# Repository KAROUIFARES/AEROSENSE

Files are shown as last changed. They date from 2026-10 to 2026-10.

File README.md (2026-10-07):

<div align="center">

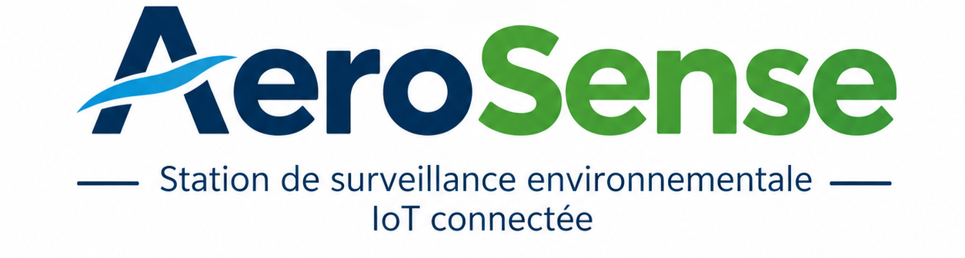
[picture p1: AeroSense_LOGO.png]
AeroSense Logo


# 🌤️ AeroSense - Station Météo Intelligente & Connectée IoT







<p align="center">
  <b>Système complet IoT de surveillance météorologique et de qualité de l'air ambiant</b><br>
  Microcontrôleur ESP32 • Capteur DHT11 • Afficheur LCD 1602 • Broker Cloud MQTT (TLS) • Dashboard Mobile Android Jetpack Compose
</p>

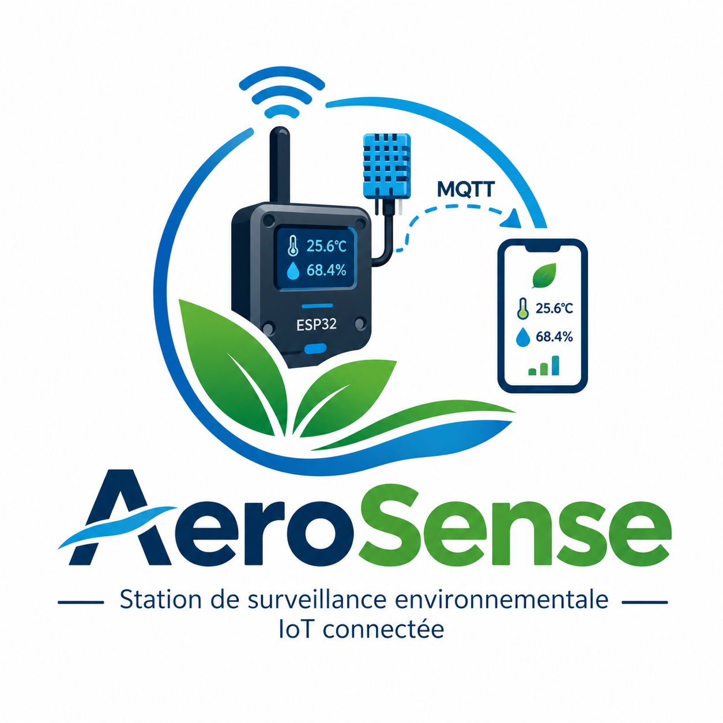
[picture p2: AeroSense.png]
AeroSense Présentation


</div>

---

## 📌 Présentation du Projet

**AeroSense** est une solution complète de station météorologique connectée pour la surveillance en temps réel de la température et de l'humidité relative. Le projet intègre l'ensemble de la chaîne de valeur d'un produit IoT :

1. **Système Embarqué (Hardware & Firmware) :**
   - Microcontrôleur **ESP32** assurant l'acquisition des données du capteur **DHT11**.
   - Affichage local instantané sur un écran **LCD 1602**.
   - Transmission sans fil sécurisée via le protocole **MQTT sur TLS/SSL (port 8883)** vers un broker Cloud.
2. **Conception Électronique & PCB :**
   - Schéma électronique et routage PCB sous **Proteus Design Suite 8**.
   - Vues et bibliothèques d'empreintes 3D (ESP32, TP4056, MT3608, USB-C, LCD 1602).
3. **Application Mobile (Dashboard Android) :**
   - Application native moderne développée en **Kotlin** avec **Jetpack Compose** et Material Design 3.
   - Connexion temps réel au broker MQTT, affichage de jauges animées, alertes automatiques et graphiques d'évolution.

---

## 📂 Structure du Répertoire

```text
AeroSense/
├── AeroSense_LOGO.png              # Logo officiel du projet
├── AeroSense.png                   # Bannière de présentation visuelle
├── Code_ESP32/                     # Firmware embarqué ESP32 (PlatformIO)
│   ├── README.md                   # Documentation technique détaillée du firmware
│   └── StationMeteo/
│       ├── platformio.ini          # Dépendances et configuration PlatformIO
│       └── src/
│           ├── config.h            # Configuration Wi-Fi et identifiants MQTT
│           └── main.cpp            # Code source principal commenté
├── ConceptionElectrique/           # Schématique et conception PCB (Proteus)
│   └── Station Météo IoT.pdsprj    # Fichier projet Proteus 8
├── Dashboard_AndroidApp/           # Application mobile Android (Jetpack Compose)
│   ├── app/src/main/
│   │   ├── java/com/.../           # Code source Kotlin (ViewModel, UI, MQTT)
│   │   └── res/                    # Ressources visuelles, icônes, thèmes
│   └── build.gradle.kts
└── Doc/                            # Documentation matérielle & bibliothèques EDA
    ├── PCB_Views/                  # Vues du circuit imprimé (PDF)
    └── Proteus_Library/            # Modèles et empreintes CAO (ESP32, LCD, etc.)
```

---

## ⚡ Architecture Système

```mermaid
flowchart LR
    A["Capteur DHT11\n(Température & Humidité)"] -->|GPIO 21| B["Microcontrôleur\nESP32"]
    B -->|Bus 4 bits| C["Afficheur LCD 1602\n(Affichage Local)"]
    B -->|Wi-Fi 802.11 b/g/n\nMQTTS / TLS Port 8883| D["Broker MQTT Cloud\n(EMQX / HiveMQ)"]
    D -->|Topic : aerosense/data\nFormat JSON| E["Application Android\nAeroSense Dashboard"]
```

---

## 🛠️ Démarrage Rapide

### 1. Firmware ESP32
Consultez la [documentation complète du firmware ESP32](./Code_ESP32/README.md).
- Rendez-vous dans `Code_ESP32/StationMeteo/`.
- Renseignez vos identifiants Wi-Fi et MQTT dans `src/config.h`.
- Téléversez avec PlatformIO : `pio run --target upload`.

### 2. Application Android Dashboard
- Ouvrez le dossier `Dashboard_AndroidApp` dans **Android Studio** (Giraffe ou version supérieure).
- Compilez et exécutez sur votre smartphone ou émulateur Android (API 26+).
- Configurez les paramètres du broker via la boîte de dialogue intégrée si nécessaire.

---

## 📄 Licence

Ce projet est sous licence MIT - voir le fichier [LICENSE](LICENSE) pour plus d'informations.

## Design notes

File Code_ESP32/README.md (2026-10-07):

# 🛰️ AeroSense - Firmware ESP32 (Station Météo IoT)

Ce sous-dossier contient le code source et la configuration PlatformIO du firmware embarqué sur le microcontrôleur **ESP32** pour la station météo connectée **AeroSense**.

---

## 📋 Table des Matières

1. [Vue d'ensemble](#-vue-densemble)
2. [Composants Matériels](#-composants-matériels)
3. [Schéma de Raccordement (Brochage / Pinout)](#-schéma-de-raccordement-brochage--pinout)
4. [Architecture Logicielle](#-architecture-logicielle)
5. [Configuration Réseau & MQTT](#-configuration-réseau--mqtt)
6. [Format des Données (Payload JSON)](#-format-des-données-payload-json)
7. [Compilation et Téléversement](#-compilation-et-téléversement)
8. [Surveillance & Débogage](#-surveillance--débogage)

---

## 🔍 Vue d'ensemble

Le firmware réalise les opérations suivantes :
- **Acquisition périodique** des mesures de température (°C) et d'humidité relative (%) via le capteur **DHT11**.
- **Affichage local temps réel** sur un écran **LCD 1602** (16 colonnes × 2 lignes) contrôlé en mode parallèle 4 bits.
- **Connexion Wi-Fi (802.11 b/g/n)** en mode station (STA).
- **Communication MQTTS sécurisée (TLS/SSL)** vers un broker Cloud (EMQX / HiveMQ Cloud sur le port 8883).
- **Publication automatique** de la télémétrie sous forme d'un objet JSON envoyé toutes les 5 secondes.

---

## 🔌 Composants Matériels

| Composant | Description | Rôle |
| :--- | :--- | :--- |
| **ESP32-WROOM-32** (NodeMCU-32S / ESP32 DevKit) | Microcontrôleur double cœur 240 MHz avec Wi-Fi & Bluetooth | Cœur de traitement et passerelle IoT |
| **DHT11** | Capteur d'ambiance numérique | Mesure de température et humidité relative |
| **LCD 1602** | Afficheur à cristaux liquides (contrôleur HD44780) | Affichage local des données et statuts |
| **Potentiomètre 10kΩ** | Potentiomètre rotatif | Ajustement du contraste du LCD (broche V0) |
| **Résistance de pull-up 4.7kΩ / 10kΩ** | Résistance de rappel | Ligne DATA du capteur DHT11 |

---

## 📌 Schéma de Raccordement (Brochage / Pinout)

### 1. Capteur DHT11
| Broche DHT11 | Broche ESP32 | Description |
| :--- | :--- | :--- |
| **VCC** | 3.3V / 5V | Alimentation capteur |
| **DATA** | **GPIO 21** | Signal de données (One-Wire) |
| **GND** | GND | Masse commune |

### 2. Afficheur LCD 1602 (Mode 4 bits)
| Broche LCD 1602 | Broche ESP32 / Circuit | Description |
| :--- | :--- | :--- |
| **Pin 1 (VSS)** | GND | Masse |
| **Pin 2 (VDD)** | 5V | Alimentation logique |
| **Pin 3 (V0)** | Curseur potentiomètre | Réglage du contraste |
| **Pin 4 (RS)** | **GPIO 27** | Register Select |
| **Pin 5 (RW)** | GND | Mode écriture (Read/Write mis à la masse) |
| **Pin 6 (E)** | **GPIO 26** | Enable (Validation) |
| **Pin 11 (D4)** | **GPIO 25** | Données bit 4 |
| **Pin 12 (D5)** | **GPIO 33** | Données bit 5 |
| **Pin 13 (D6)** | **GPIO 32** | Données bit 6 |
| **Pin 14 (D7)** | **GPIO 14** | Données bit 7 |
| **Pin 15 (A)** | 5V (via résistance 220Ω) | Rétroéclairage Anode (+) |
| **Pin 16 (K)** | GND | Rétroéclairage Cathode (-) |

---

## 🏗️ Architecture Logicielle

Le projet est structuré selon les standards **PlatformIO** :

```text
Code_ESP32/StationMeteo/
├── platformio.ini       # Configuration du projet, de la cible et des dépendances
├── include/             # Fichiers d'en-tête additionnels
├── lib/                 # Bibliothèques privées du projet
├── src/
│   ├── config.h         # Constantes de configuration Wi-Fi et broker MQTT
│   └── main.cpp         # Logique principale (Setup, Loop, MQTT, DHT, LCD)
└── test/                # Tests unitaires
```

### Dépendances (`platformio.ini`) :
- `adafruit/DHT sensor library@^1.4.7` : Pilote de communication avec le capteur DHT11.
- `arduino-libraries/LiquidCrystal@^1.0.7` : Gestion de l'écran LCD 1602 (standard HD44780).
- `knolleary/PubSubClient@^2.8` : Client MQTT léger pour microcontrôleurs.

---

## ⚙️ Configuration Réseau & MQTT

Toutes les informations d'identification se trouvent dans `src/config.h` :

```cpp
// --- Configuration Wi-Fi ---
#define WIFI_SSID     "VOTRE_SSID_WIFI"
#define WIFI_PASSWORD "VOTRE_MOT_DE_PASSE"

// --- Configuration Broker Cloud ---
#define MQTT_BROKER   "h1211a42.ala.eu-central-1.emqxsl.com" // Hôte EMQX / HiveMQ
#define MQTT_PORT     8883                                   // Port MQTTS chiffré TLS
#define MQTT_USER     "KAROUI"                               // Identifiant MQTT
#define MQTT_PASS     "aerosense"                            // Mot de passe MQTT

// --- Topics ---
#define MQTT_TOPIC_DATA "aerosense/data"                     // Topic de télémétrie
```

> **Sécurité TLS :** La couche réseau utilise `WiFiClientSecure` avec l'option `espClient.setInsecure()` pour dialoguer de façon chiffrée (SSL/TLS sur le port 8883) avec le broker sans nécessiter d'embarquer les certificats racines volumineux.

---

## 📦 Format des Données (Payload JSON)

Le firmware encapsule les mesures et les transmet sur le sujet MQTT `aerosense/data` :

```json
{
  "temp": 24.5,
  "hum": 60.0
}
```

- `temp` : Température mesurée en degrés Celsius (°C), arrondi à 1 décimale.
- `hum` : Humidité relative mesurée en pourcentage (%), arrondi à 1 décimale.

Ce format est directement décodé en temps réel par l'application Android **AeroSense Dashboard**.

---

## 🚀 Compilation et Téléversement

### Prérequis
- [Visual Studio Code](https://code.visualstudio.com/) avec l'extension **PlatformIO IDE**, ou la CLI PlatformIO (`pip install platformio`).

### Commandes en ligne de commande (CLI)

1. **Ouvrir le dossier :**
   ```bash
   cd Code_ESP32/StationMeteo
   ```

2. **Compiler le firmware :**
   ```bash
   pio run
   ```

3. **Téléverser sur l'ESP32 :**
   ```bash
   pio run --target upload
   ```

4. **Ouvrir le moniteur série (115200 bauds) :**
   ```bash
   pio device monitor -b 115200
   ```

---

## 🖥️ Surveillance & Débogage

Au démarrage, le moniteur série affiche le statut complet de la station :
```text
[AeroSense] Démarrage du système...
[AeroSense] Capteur DHT11 initialisé.
[AeroSense] Connexion au Wi-Fi : Topnet_12P8
.....
[AeroSense] Wi-Fi connecté !
[AeroSense] Adresse IP locale : 192.168.1.55
[AeroSense] Configuration MQTT appliquée.
[AeroSense] Tentative de connexion au broker MQTT... Connecté !
[AeroSense] Température: 24.2 °C | Humidité: 58.0 %
[AeroSense] Données publiées avec succès sur MQTT.
```

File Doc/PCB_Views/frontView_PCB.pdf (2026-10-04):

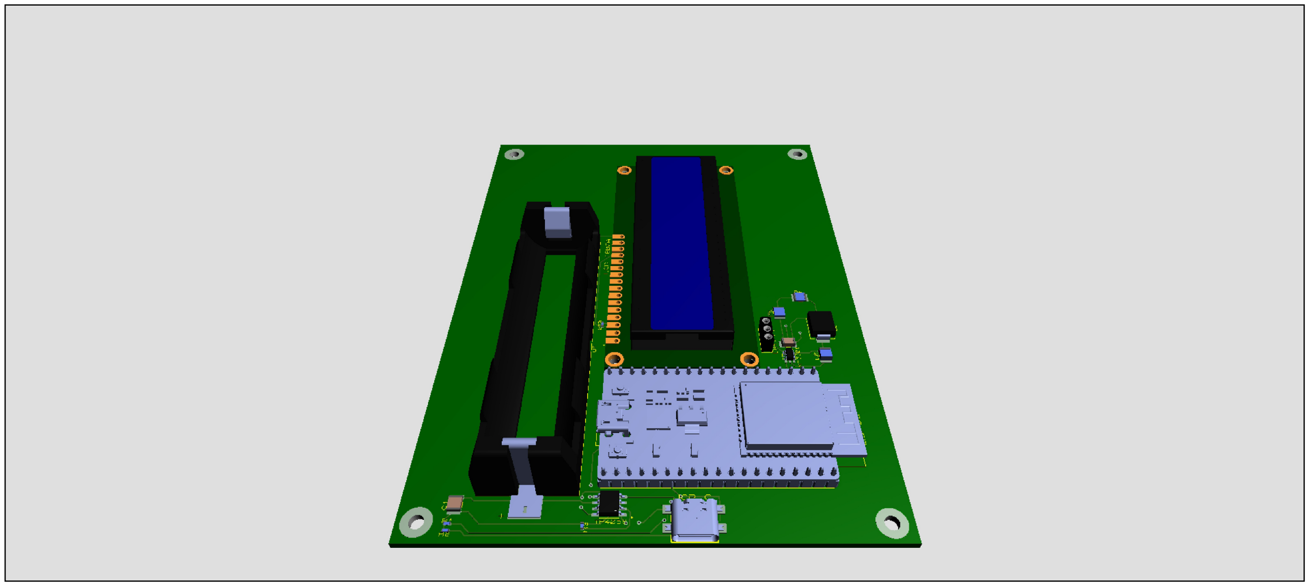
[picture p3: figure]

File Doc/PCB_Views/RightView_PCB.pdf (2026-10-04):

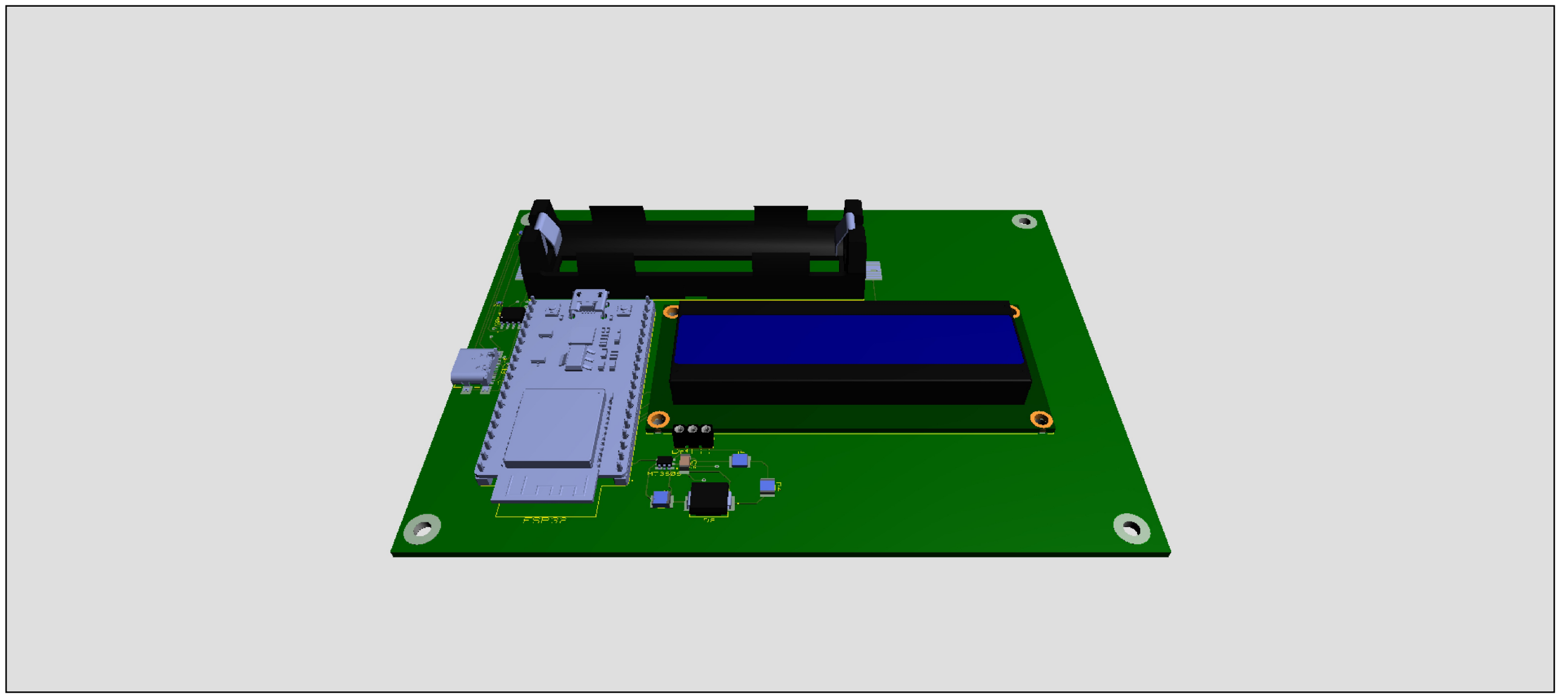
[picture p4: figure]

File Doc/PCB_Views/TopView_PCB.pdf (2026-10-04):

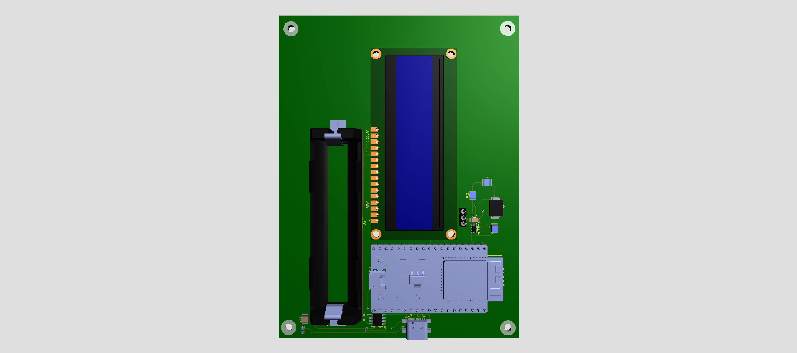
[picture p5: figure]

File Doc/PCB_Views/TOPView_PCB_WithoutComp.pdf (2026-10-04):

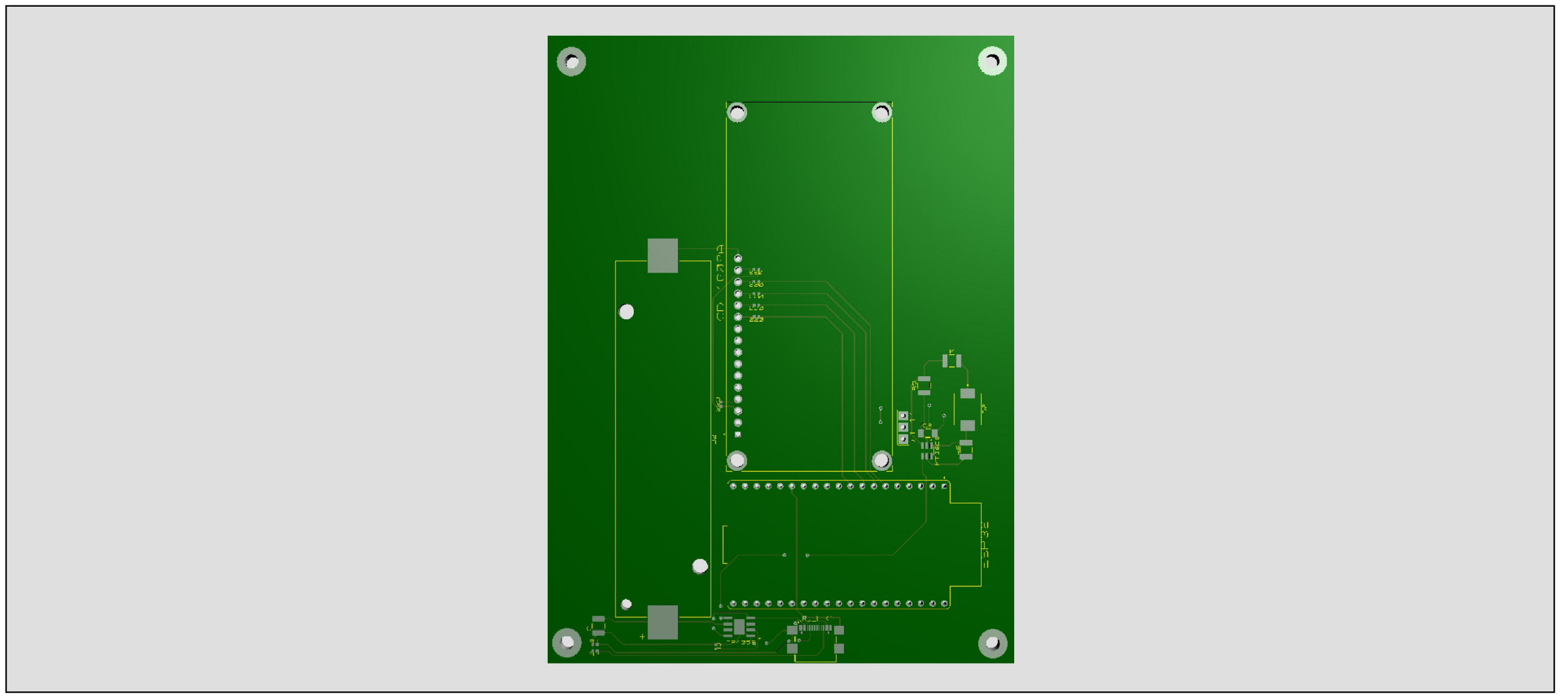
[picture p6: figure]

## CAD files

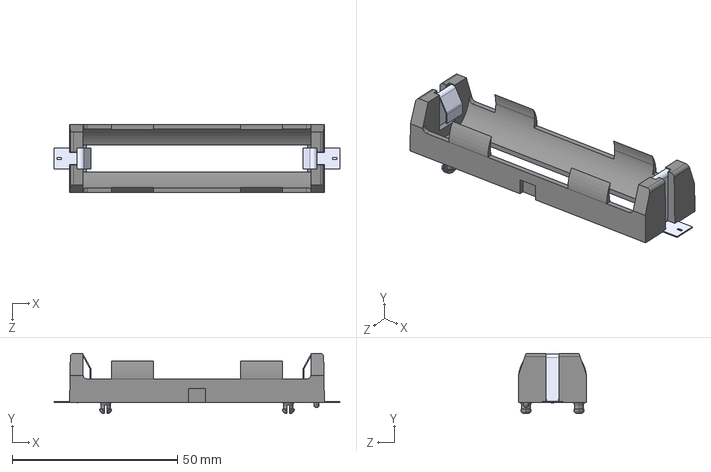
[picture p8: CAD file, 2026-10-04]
Doc/Proteus_Library/1042/1042.step
86.5 x 18.3 x 20.7 mm

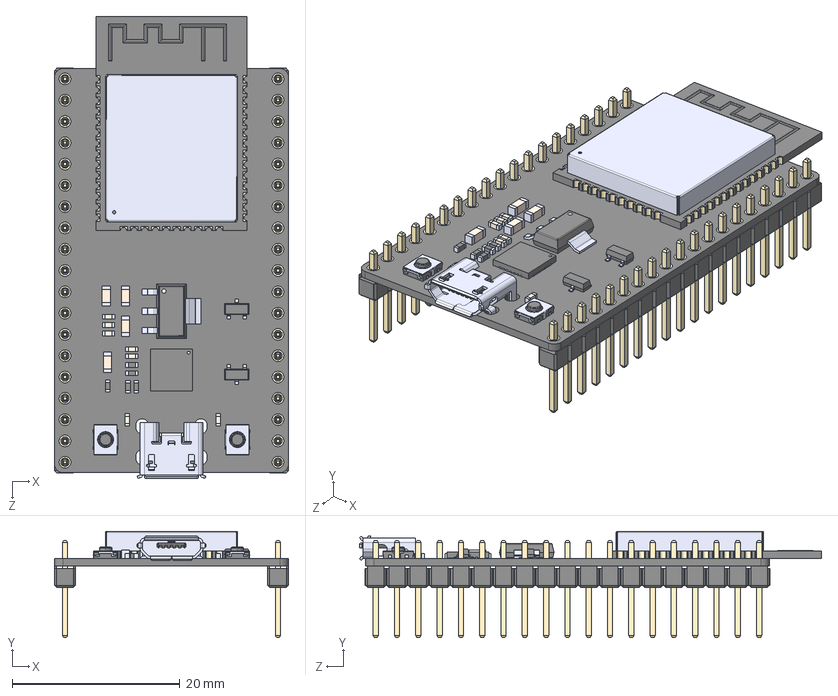
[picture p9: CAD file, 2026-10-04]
Doc/Proteus_Library/ESP32-DEVKITC-32E/ESP32-DEVKITC-32E.step
27.9 x 12.7 x 55.1 mm
board
header x 2
ESP32-WROOM-32D
micro usb
button x 2
CP2102N-A01-GQFN28
AMS1117-3.3
SS8050-G
components^DEVKIT V1 ESP32-WROOM-32

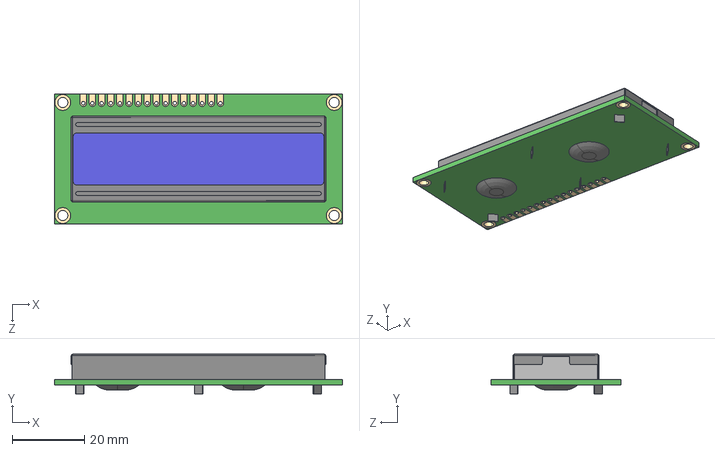
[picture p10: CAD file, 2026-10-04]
Doc/Proteus_Library/LCD_1602_2X16_BLUE-WHITE/LCD_1602_2X16_BLUE-WHITE.step
80.0 x 11.0 x 36.0 mm

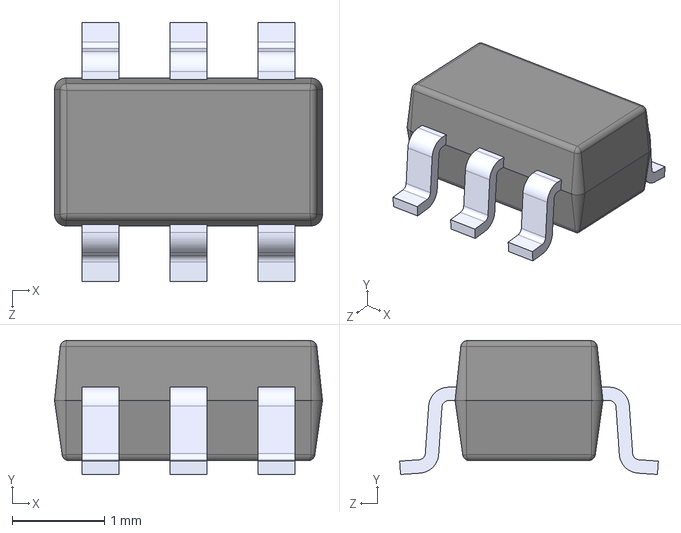
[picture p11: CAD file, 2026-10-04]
Doc/Proteus_Library/MT3608/MT3608.step
2.90 x 1.45 x 2.80 mm

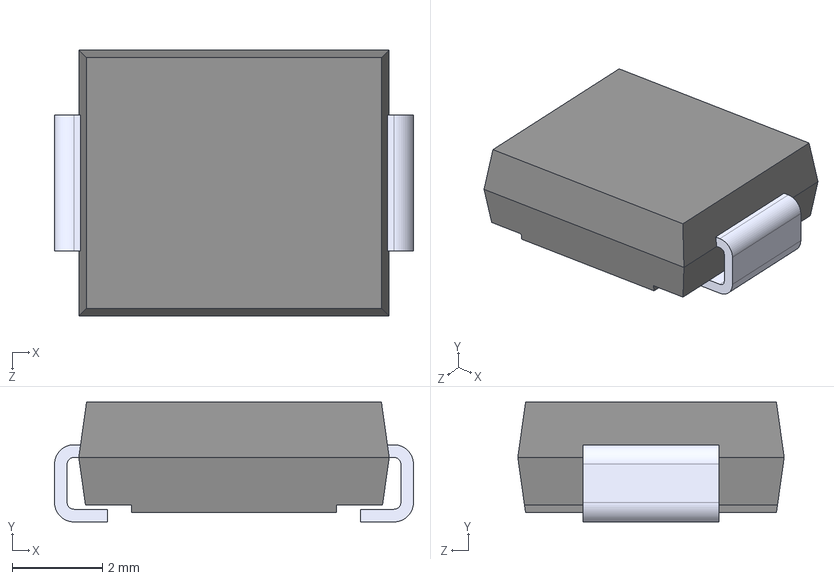
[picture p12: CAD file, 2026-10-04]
Doc/Proteus_Library/SS34/SS34.step
7.95 x 2.65 x 5.90 mm

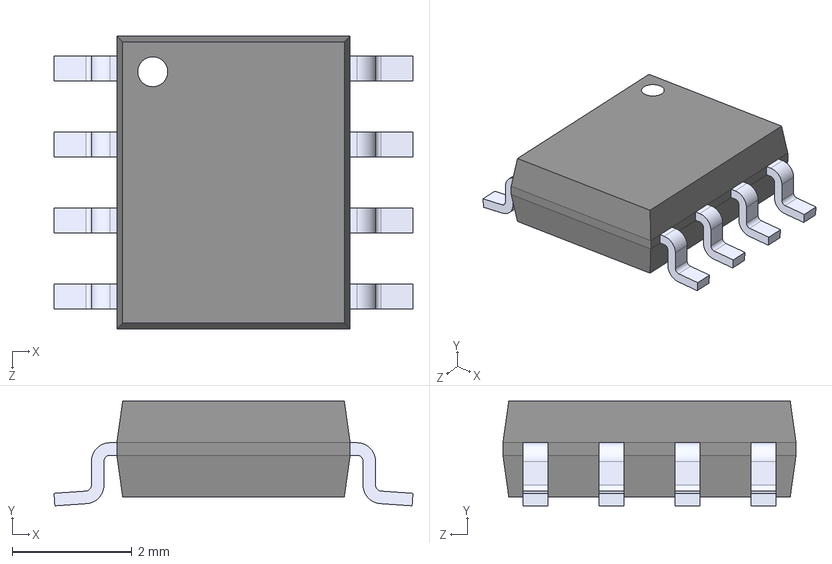
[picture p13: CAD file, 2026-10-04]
Doc/Proteus_Library/TP4056/TP4056.step
6.00 x 1.75 x 4.90 mm

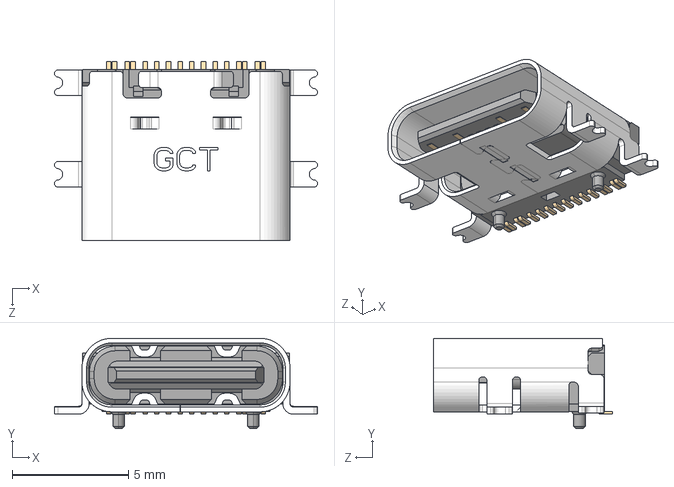
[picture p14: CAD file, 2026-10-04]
Doc/Proteus_Library/USB4110GFA/USB4110GFA.step
11.3 x 3.89 x 7.70 mm

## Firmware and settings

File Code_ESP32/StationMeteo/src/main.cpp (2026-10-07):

/**
 * ============================================================================
 * @file       main.cpp
 * @brief      Firmware ESP32 pour la Station Météo Connectée AeroSense
 * @project    AeroSense - Station Météo IoT
 * @details    Ce programme réalise :
 *             1. L'initialisation du matériel (Afficheur LCD 1602 et Capteur DHT11).
 *             2. La connexion au point d'accès Wi-Fi local.
 *             3. La connexion sécurisée en TLS/SSL au broker Cloud MQTT.
 *             4. La lecture périodique des mesures de température et d'humidité.
 *             5. L'encapsulation des mesures au format JSON et publication MQTT.
 *             6. L'affichage local et continu des grandeurs sur l'écran LCD.
 * ============================================================================
 */

#include <Arduino.h>
#include <DHT.h>
#include <LiquidCrystal.h>

#include <WiFi.h>
#include <WiFiClientSecure.h>
#include <PubSubClient.h>

#include "config.h"

// ============================================================================
// DÉFINITIONS MATÉRIELLES & BROCHAGE (PINOUT)
// ============================================================================

/** @brief Broche GPIO connectée à la ligne DATA du capteur DHT11 */
const int DHTPIN = 21;

/** @brief Type de capteur utilisé (DHT11, DHT22 ou DHT21) */
#define DHTTYPE DHT11

/**
 * @brief Instance du pilote pour le capteur d'ambiance DHT11
 * @param DHTPIN  GPIO 21 (Données avec résistance de pull-up)
 * @param DHTTYPE DHT11
 */
DHT dht(DHTPIN, DHTTYPE);

/**
 * @brief Configuration de l'afficheur LCD 16x2 en mode parallèle 4 bits
 * @param rs GPIO 27 (Register Select : choix commande ou donnée)
 * @param en GPIO 26 (Enable : impulsion de validation)
 * @param d4 GPIO 25 (Bus de données bit 4)
 * @param d5 GPIO 33 (Bus de données bit 5)
 * @param d6 GPIO 32 (Bus de données bit 6)
 * @param d7 GPIO 14 (Bus de données bit 7)
 */
LiquidCrystal lcd(27, 26, 25, 33, 32, 14);

// ============================================================================
// CLIENTS RÉSEAU & SÉCURITÉ TLS/MQTT
// ============================================================================

/** 
 * @brief Client Wi-Fi avec support de chiffrement TLS/SSL
 * @note  Permet d'établir une liaison sécurisée avec le port MQTTS 8883.
 */
WiFiClientSecure espClient;

/** 
 * @brief Gestionnaire de messages et protocole MQTT (PubSubClient)
 * @note  S'appuie sur le socket TLS fourni par espClient.
 */
PubSubClient client(espClient);

// ============================================================================
// PROTOTYPES DES FONCTIONS
// ============================================================================

/**
 * @brief Établit ou rétablit la connexion avec le broker MQTT Cloud.
 *        Boucle jusqu'à l'obtention d'une liaison active.
 */
void connectMQTT();

// ============================================================================
// INITIALISATION DU SYSTÈME (SETUP)
// ============================================================================

/**
 * @brief Initialisation des périphériques matériels et des interfaces réseau.
 *        Exécuté une seule fois à la mise sous tension ou au redémarrage.
 */
void setup()
{
  // 1. Initialisation de la communication série pour le débogage (115200 bauds)
  Serial.begin(115200);
  Serial.println("\n[AeroSense] Démarrage du système...");

  // 2. Initialisation de l'afficheur LCD (16 colonnes, 2 lignes)
  lcd.begin(16, 2);
  lcd.clear();
  lcd.setCursor(0, 0);
  lcd.print("AEROSENSE...");
  lcd.setCursor(0, 1);
  lcd.print("Initialisation");

  // 3. Initialisation du capteur DHT11
  dht.begin();
  Serial.println("[AeroSense] Capteur DHT11 initialisé.");

  // 4. Connexion au réseau Wi-Fi
  Serial.print("[AeroSense] Connexion au Wi-Fi : ");
  Serial.println(WIFI_SSID);
  WiFi.mode(WIFI_STA);
  WiFi.begin(WIFI_SSID, WIFI_PASSWORD);

  while (WiFi.status() != WL_CONNECTED)
  {
    delay(500);
    Serial.print(".");
  }
  Serial.println("\n[AeroSense] Wi-Fi connecté !");
  Serial.print("[AeroSense] Adresse IP locale : ");
  Serial.println(WiFi.localIP());

  // 5. Configuration de la couche de sécurité TLS
  // setInsecure désactive la validation stricte de la chaîne de certificats racine
  // ce qui est optimal pour les microcontrôleurs légers accédant au cloud.
  espClient.setInsecure();

  // 6. Configuration du serveur MQTT
  client.setServer(MQTT_BROKER, MQTT_PORT);
  Serial.println("[AeroSense] Configuration MQTT appliquée.");

  // 7. Message d'accueil temporaire sur l'écran LCD
  lcd.clear();
  lcd.setCursor(0, 0);
  lcd.print("AEROSENSE...");
  lcd.setCursor(0, 1);
  lcd.print("Station Prete !");
  delay(3000);
  lcd.clear();
}

// ============================================================================
// BOUCLE PRINCIPALE D'EXÉCUTION (LOOP)
// ============================================================================

/**
 * @brief Cycle principal du firmware :
 *        - Maintien du lien MQTT
 *        - Échantillonnage des données météo
 *        - Envoi télémétrique JSON
 *        - Mise à jour de l'affichage local
 */
void loop()
{
  // 1. Vérification et rétablissement de la liaison MQTT si nécessaire
  if (!client.connected())
  {
    connectMQTT();
  }
  client.loop(); // Traitement des événements réseau MQTT (keep-alive / ping)

  // 2. Acquisition des mesures physiques depuis le capteur DHT11
  float temperature = dht.readTemperature();
  float humidity = dht.readHumidity();

  // 3. Contrôle de validité des mesures reçues
  if (isnan(temperature) || isnan(humidity))
  {
    Serial.println("[AeroSense] Avertissement : Échec de lecture du capteur DHT11 !");
    lcd.setCursor(0, 0);
    lcd.print("Erreur DHT11    ");
  }
  else
  {
    // Affichage des informations sur le moniteur série
    Serial.printf("[AeroSense] Température: %.1f °C | Humidité: %.1f %%\n", temperature, humidity);

    // 4. Construction de la charge utile (Payload) au format JSON
    // Format : {"temp": 24.50, "hum": 60.00}
    String payload = "{\"temp\":" + String(temperature, 1) + ",\"hum\":" + String(humidity, 1) + "}";

    // 5. Publication de la télémétrie sur le topic MQTT configuré
    if (client.publish(MQTT_TOPIC_DATA, payload.c_str()))
    {
      Serial.println("[AeroSense] Données publiées avec succès sur MQTT.");
    }
    else
    {
      Serial.println("[AeroSense] Erreur lors de la publication MQTT.");
    }

    // 6. Mise à jour des indications sur l'afficheur LCD 1602
    // Ligne 1 : Température en °C
    lcd.setCursor(0, 0);
    lcd.print("Temp : ");
    lcd.print(temperature, 1);
    lcd.print(" \xDF" "C   "); // \xDF correspond au symbole degré '°' sur HD44780

    // Ligne 2 : Humidité relative en %
    lcd.setCursor(0, 1);
    lcd.print("Hum  : ");
    lcd.print(humidity, 1);
    lcd.print(" %    ");
  }

  // 7. Intervalle d'attente avant la prochaine mesure (5 secondes)
  delay(5000);
}

// ============================================================================
// GESTIONNAIRE DE CONNEXION MQTT
// ============================================================================

/**
 * @brief Assure la négociation de session avec le broker MQTT Cloud.
 *        Réitère la tentative toutes les 2 secondes en cas d'échec.
 */
void connectMQTT()
{
  while (!client.connected())
  {
    Serial.print("[AeroSense] Tentative de connexion au broker MQTT...");
    String clientId = "ESP32_AeroSense";

    // Tentative de connexion avec identification et mot de passe
    if (client.connect(clientId.c_str(), MQTT_USER, MQTT_PASS))
    {
      Serial.println(" Connecté !");
      lcd.setCursor(0, 1);
      lcd.print("Broker Connecte!");
      delay(1000);
      lcd.clear();
    }
    else
    {
      Serial.printf(" Échec (rc = %d). Nouvelle tentative dans 2s...\n", client.state());
      lcd.setCursor(0, 1);
      lcd.print("Attente MQTT... ");
      delay(2000);
    }
  }
}

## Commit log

2026-10-04 Initial commit - AEROSENSE Weather Station Project
    [1042.step, ESP32-DEVKITC-32E.step, LCD_1602_2X16_BLUE-WHITE.step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]
2026-10-06 feat: add Android dashboard app, update ESP32 firmware, Proteus schematic and branding assets
2026-10-07 docs(esp32): documenter le firmware ESP32 et mettre à jour la station météo
    - Ajout de la documentation complète et détaillée dans main.cpp et config.h (Doxygen / C++)
    - Ajout du guide technique Code_ESP32/README.md (brochage, MQTT TLS, JSON, PlatformIO)
    - Restructuration du dossier de code sous Code_ESP32/StationMeteo
    - Ajout du README.md racine pour la présentation globale du projet AeroSense
    - Mises à jour de l'application Android Dashboard (SplashScreen, icônes, compatibilité télémétrie)

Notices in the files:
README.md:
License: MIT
